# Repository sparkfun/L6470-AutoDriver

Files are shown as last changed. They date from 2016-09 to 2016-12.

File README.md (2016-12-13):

SparkFun AutoDriver - Stepper Motor Driver
==========================================

AutoDriver  

[*AutoDriver (BOB-13752)*](https://www.sparkfun.com/products/13752)

The AutoDriver is a bipolar stepper driver based on the ST Micro L6470 chip. It allows a processor to control a single 3A bipolar stepper motor across an 8-45V supply range.

Repository Contents
-------------------
* **/Hardware** - All Eagle design files (.brd, .sch)
* **/Libraries** - All Arduino libraries and board examples
* **/Production** - Test bed files and production panel files

Documentation
--------------
* **[Library](https://github.com/sparkfun/SparkFun_AutoDriver_Arduino_Library)** - Arduino library for the AutoDriver.
* **[Hookup Guide](https://learn.sparkfun.com/tutorials/getting-started-with-the-autodriver---v13)** - Basic hookup guide for the Auto Driver.
* **[SparkFun Fritzing repo](https://github.com/sparkfun/Fritzing_Parts)** - Fritzing diagrams for SparkFun products.
* **[SparkFun 3D Model repo](https://github.com/sparkfun/3D_Models)** - 3D models of SparkFun products. 
* **[SparkFun Graphical Datasheets](https://github.com/sparkfun/Graphical_Datasheets)** -Graphical Datasheets for various SparkFun products.

License Information
-------------------

This product is _**open source**_! 

Please review the LICENSE.md file for license information. 

If you have any questions or concerns on licensing, please contact techsupport@sparkfun.com.

Distributed as-is; no warranty is given.

- Your friends at SparkFun.

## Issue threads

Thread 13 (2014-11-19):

Board issues

lewispg228, 2014-11-19:
1) I think we may want to go with the "PANASONIC_E" package for C3. "PANASONIC_C" is the current package, and when you compare it to a scaled product image, it looks too small:
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

2) Dimension line is 0.010, should be 0.008

3) Would it be beneficial if we pre-populated all of the PTH connectors with the SS? If so, we should move the packages to locking style.

4) Please add test point to 3.3V net

5) JP1 2 3 and 4, and R4 do not have >NAME text object in the package.

6) remove the M.Hord text object on tvalues

7) add dimension measurements onto the measures layer 47

8) The HTSSOP28 packages used on the L6470 needs it's outline silk bumped up to 8 mil. same thing for trimpot (R4)

9) What does the switch do? Can we add any schematic note and/or board silk to be more descriptive than "SWITCH"

10) Can we add some silk boxes around the GND MOTOR pins, and POWER pins to more clearly shot that each pin is doubled up.

11) Can we scoot the 3 way jumper out a bit so the labeling can be more uniform (that is, each label being on each outer side of the jumper) Or just scoot C8 up a bit so the "3.3V" can live directly above jumper.

12) Looks like there are 4 active low pins on the L6470. We should probably get those updated in the symbol to show that.

13) We should probably add some silk to label the trimpot. Maybe just "Trimpot to ADCIN".

lewispg228, 2015-01-14:
Sorry to have left this linger so long. I'm not sure how it fell off my radar.

I just did some printing and it looks like all the panasonic packages are wrong. But there is a device for the NIC 10X10.5 cap that is correct.

mhord, 2015-04-22:
The NIC package is the one that's on there; the first round of protos (with the bad cam job) came back looking good.

lewispg228, 2015-04-22:
Sorry I was looking at the wrong tree. Here's my review of v11 on the qc-rev:

1) Does the frame have the proper CC attribution? (Frame- Letter/Ledger, CC 4.0) [NO]
comment: Needs latest frame to avoid panelization problem regarding copper version

2) Is 'Revised by:' and 'reviser name' included? [YES]
comment: move back into frame box

3) Are dashed grey lines ('info' eagle layer 97) used to clearly separate different areas? [NO]
comment: dashed lines are currently on symbols layer, should be info

4) Is the VCC range clearly labeled? [NO]
comment: needs vcc range in sch

5) Do any parts have unnecessary values (Eagle has autoset the package as the value)? [YES]
comment: SJ3 JP1 JP2

6) Does your 4 layer board include mike hord's special '1' '2' '3' '4' in the copper of each layer? [NO]
comment: this is nice fore gerber verification

7) Are any vias intended to be used as PTH headers (they shouldn't be)? [YES]
comment: The CSN via should be an actual M01 device

8) Is there a correct version number in the copper? [NO]
comment: copper version is outside dimension of board

9) Are measurements included for outer dimension and standoffs (Eagle layer 47)? [NO]
comment: needs measures

mhord, 2015-04-22:
Killer. I'll make these changes along with anything we find out from this round of re-cammed protos.

lewispg228, 2015-04-24:
Thanks Mike.

I think production (Nick Harmier or Austin Metzger) is waiting for us to finalize this review before they re-cam it up and order another round of protos.

They won't order any protos until they see (1) uploaded complete review Excell doc and (2) the review flag set to "+".

mhord, 2015-04-30:
Fixed.

Closed 2015-04-30.

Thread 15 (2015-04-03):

Making the library compatible with Teensy

PheiPheiPhei, 2015-04-03:
Hi!

[I came across a simple fix that will make the library compatible with Teensy microcontrollers.](https://forum.pjrc.com/threads/28094-L6470-AutoDriver-stepper-driver-and-the-Teensy-3-1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) Simply declaring all chars explicitly as signed will fix it.

ToniCorinne, 2016-03-09:
Hi -we'd love it if you added a pull request with this fix to the main library repository [here](https://github.com/sparkfun/SparkFun_AutoDriver_Arduino_Library). That will allow us to give you credit for the fix.

Thanks!

PheiPheiPhei, 2016-03-09:
Hi!

I'm sadly a pretty big noob with Git and don't know how to do that. But go
ahead, I don't insist on credit. :)

2016-03-09 1:18 GMT+01:00 Toni Klopfenstein <notifications@github.com>:

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

christophepersoz, 2016-04-04:
Hello guys,

I'm trying to make the library working with a simple example (run, stop, back run), but it seems that something is going wrong just after sending the goToDir command. As soon as the stepper start to run until the position and after it reach the position the loop() completely stop.
Do you have this kind of issue too ?

Thanks

christophepersoz, 2016-04-25:
In order to make the library completely compatible with Teensy I had to change the SparkFunAutoDriverCommands.cpp in the same way that @PheiPheiPhei did on xferParam() and signed all the char in the file. That way, when you call GoTo() command or any other referring to SPIXfer() the behavior is now OK.

I hope it could help.

mhord, 2016-08-16:
Fixed during refactoring by changing data type to int8_t (aka signed char) from char. Thanks for the tip!

Closed 2016-08-16.

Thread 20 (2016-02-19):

dSPIN_support:165 error

castfxman, 2016-02-19:
Hello,

I have used your example with success and recent reinstalled my 1.5.3 IDE and am getting a new error on line 165 of dSPIN_support it looks like

`  dSPIN_support:165: error: 'SPI_CLOCK_DIV16' was not declared in this scope`

Any ideas where this error could be coming from?  Thanks!

mgrusin, 2016-02-22:
It looks like setClockDivider() may have been depreciated: https://www.arduino.cc/en/Reference/SPISetClockDivider. We apologize for the inconvenience; the newest Arduino IDEs have been breaking a lot of things.

Thanks for the error report, we'll look into it!

castfxman, 2016-02-22:
Yes, in 1.5.8 version did not get this error, I tried to not include the SPI_CLOCK_DIV16 line in the 1.5.3 version which I think pumped unregulated hertz into the boards motor drivers.  I did in fact fry/smoke/burnout a couple L6470 drivers by eliminating that SPI _Clock_div16 line, but it is properly declared in 1.5.8.  SPI.h file.  So I'm using that or later from now on.

Closed 2016-02-22.

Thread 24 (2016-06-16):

Renumber solder jumpers and sj description text

mhord, 2016-06-16:

mhord, 2016-06-16:
Fixed...made into SJ3 (SJ2 is the PGND-GND jumper)

Closed 2016-06-16.

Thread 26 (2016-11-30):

AutoDriver ABS_POS problems

philk557, 2016-11-30:
About two months ago I ordered an L6470 AutoDrive V13 board from SparkFun to use with a machine tool rotary table. I have gotten the board to work with an Arduino Mega and a 34 vdc power supply.

However the position count from ADboard.getParam (ABS_POS) has problems:

1.     Even with the board set to full stepping, ADboard.configStepMode(STEP_FS),
       ABS_POS increments by about 128 microsteps instead of full steps.

2.     The count appears to be modulo 2**16 unsigned instead of 2**21 two’s complement.

For example (the decimal numbers are 2**16 unsigned):

When ABS_POS is incremented from  0x007FFF (32,767), ABS_POS is set to 0x3F8000 (32,768).
When ABS_POS is incremented from  0x3FFFFF (65,535), ABS_POS is set to 0x000000.
When ABS_POS is decremented from 0x000000,             ABS_POS is set to 0x3FFFFF (65,535)
When ABS_POS is decremented from 0x3F8000 (32,768), ABS_POS is set to 0x007FFF (32,767).

ADboard.getPos() interprets the count as 2**21 two’s complement.

When  the count reaches 0x007FFF (32,767), it rolls over to 0xFFFF8000 (-32,768)..

Following are portions of a monitor log file of readings once a second.

get_pos is the value return by long getPos(); first HEX then DEC.
ABS_POS is the value returned by unsigned long getParam(ABS_POS), first HEX the DEC
&0x00FFFF is the ABS_POS value masked by &0x00FFFF, first HEX then DEC.

  10:2:22 Run FWD 1.00 steps/sec for 20 secs
  get_pos: 7EB9 32441  ABS_POS: 7EB9  &0x00FFFF 7EB9 32441
  get_pos: 7F3B 32571  ABS_POS: 7F3B  &0x00FFFF 7F3B 32571
  get_pos: 7FBE 32702  ABS_POS: 7FBE  &0x00FFFF 7FBE 32702
  get_pos: FFFF8040 -32704  ABS_POS: 3F8040  &0x00FFFF 8040 32832
  get_pos: FFFF80C2 -32574  ABS_POS: 3F80C2  &0x00FFFF 80C2 32962
  get_pos: FFFF8144 -32444  ABS_POS: 3F8144  &0x00FFFF 8144 33092

  get_pos: FFFFFE87 -377  ABS_POS: 3FFE87  &0x00FFFF FE87 65159
  get_pos: FFFFFF09 -247  ABS_POS: 3FFF09  &0x00FFFF FF09 65289
  get_pos: FFFFFF8B -117  ABS_POS: 3FFF8B  &0x00FFFF FF8B 65419
  get_pos: D 13  ABS_POS: D  &0x00FFFF D 13
  get_pos: 8F 143  ABS_POS: 8F  &0x00FFFF 8F 143
  get_pos: 112 274  ABS_POS: 112  &0x00FFFF 112 274

10:17:54 Run REV 1.00 steps/sec for 20 secs
  get_pos: 174 372  ABS_POS: 174  &0x00FFFF 174 372
  get_pos: F1 241  ABS_POS: F1  &0x00FFFF F1 241
  get_pos: 6F 111  ABS_POS: 6F  &0x00FFFF 6F 111
  get_pos: FFFFFFED -19  ABS_POS: 3FFFED  &0x00FFFF FFED 65517
  get_pos: FFFFFF6B -149  ABS_POS: 3FFF6B  &0x00FFFF FF6B 65387
  get_pos: FFFFFEE9 -279  ABS_POS: 3FFEE9  &0x00FFFF FEE9 65257

  get_pos: FFFF8144 -32444  ABS_POS: 3F8144  &0x00FFFF 8144 33092
  get_pos: FFFF80C1 -32575  ABS_POS: 3F80C1  &0x00FFFF 80C1 32961
  get_pos: FFFF803F -32705  ABS_POS: 3F803F  &0x00FFFF 803F 32831
  get_pos: 7FBD 32701  ABS_POS: 7FBD  &0x00FFFF 7FBD 32701
  get_pos: 7F3B 32571  ABS_POS: 7F3A  &0x00FFFF 7F3A 32570
  get_pos: 7EB8 32440  ABS_POS: 7EB8  &0x00FFFF 7EB8 32440

mhord, 2016-11-30:
Give it a try now. I fixed a logic error in the shifting of incoming SPI data that only affected parameters of greater than 16 bits.

philk557, 2016-11-30:
Hello Mike

Great!  You fixed it.

Do I download a new version of the AutoDriver library to get the fix?

Thanks

Phil

At 02:55 PM 11/30/2016, you wrote:

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

mhord, 2016-12-01:
You can either download it, clone it, or pull the changes. Downloading is probably easiest if you aren't already doing a lot of stuff via github.

philk557, 2016-12-02:
Hi Mike

I deleted the old AutoDriver library, download
the AutoDriver ZIP file from GitHub and added the
new library.  I didnt see any change notice in
the header so I assumed I got your fix.

There are still problems.

In the following logs, the first get_pos number
is HEX, the second is DEC and the third is the
difference from the previous reading DEC.  All
get_pos numbers are printed as LONG.  The ABS_POS is HEX.

1.  ADboard.getPos()is still reporting about 130
steps per full step, ADboard.configStepMode(STEP_FS).

11:9:40 Run FWD 1.00 steps/sec for 10 secs
11:9:40   get_pos: 1 1 1  ABS_POS: 3
11:9:42   get_pos: 87 135 134  ABS_POS: 87
11:9:43   get_pos: 109 265 130  ABS_POS: 109
11:9:44   get_pos: 18C 396 131  ABS_POS: 18C
11:9:45   get_pos: 20E 526 130  ABS_POS: 20E
11:9:46   get_pos: 290 656 130  ABS_POS: 290
11:9:47   get_pos: 312 786 130  ABS_POS: 313
11:9:48   get_pos: 395 917 131  ABS_POS: 395
11:9:49   get_pos: 417 1047 130  ABS_POS: 417
11:9:50   get_pos: 499 1177 130  ABS_POS: 49A
11:9:51   get_pos: 51C 1308 131  ABS_POS: 51C
elapsed ms= 11141

2.      Since AB_POS is a 22 bit register with a
signed number, I expected 2FFFFF to overflow to 0?  Not to keep on incrementing

11:12:41 Run FWD 400.00 steps/sec for 30 secs
11:12:51   get_pos: 2D2109 2957577 52226  ABS_POS: 2D2143
11:12:52   get_pos: 2DECDC 3009756 52179  ABS_POS: 2DED16
11:12:53   get_pos: 2EB8F4 3062004 52248  ABS_POS: 2EB92D
11:12:54   get_pos: 2F850B 3114251 52247  ABS_POS: 2F8545
11:12:55   get_pos: 305120 3166496 52245  ABS_POS: 305159
11:12:56   get_pos: 311D28 3218728 52232  ABS_POS: 311D61
11:12:57   get_pos: 31E928 3270952 52224  ABS_POS: 31E962
11:12:58   get_pos: 32B526 3323174 52222  ABS_POS: 32B560

11:13:20   get_pos: 3DF997 4061591 11  ABS_POS: 3DFA50
11:13:21   get_pos: 3EBD37 4111671 50080  ABS_POS: 3EBD70
11:13:22   get_pos: 3F893A 4163898 52227  ABS_POS: 3F8973
11:13:23   get_pos: 5547 21831 -4142067  ABS_POS: 557C
11:13:24   get_pos: 12153 74067 52236  ABS_POS: 12185
11:13:25   get_pos: 1ED64 126308 52241  ABS_POS: 1ED99
11:13:26   get_pos: 2B973 178547 52239  ABS_POS: 2B9A7

3.      Following is what happened when
decrementing past 0.  I expected the next count
to be minus.  It looks like the minus bit wasnt propagated to the left.

11:40:29   get_pos: 18B 395 -130  ABS_POS: 18B
11:40:30   get_pos: 108 264 -131  ABS_POS: 108
11:40:31   get_pos: 86 134 -130  ABS_POS: 86
11:40:32   get_pos: 4 4 -130  ABS_POS: 4
11:40:33   get_pos: 3FFF81 4194177 4194173  ABS_POS: 3FFF81
11:40:34   get_pos: 3FFEFF 4194047 -130  ABS_POS: 3FFEFF
11:40:35   get_pos: 3FFE7D 4193917 -130  ABS_POS: 3FFE7C

At 02:55 PM 11/30/2016, you wrote:

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

mhord, 2016-12-05:
1. Can you post your code somewhere? I can't duplicate the stepping issue. What does the actual motor seem to be doing? If you move forward at 1step/s, does it move a full revolution in the expected time?
2. Overflow of signed integers is left to the compiler author's imagination; there's no standard for it, so anything that happens is fair game. It looks like if you go far enough past -2^21 eventually something weird happens and you end up with a large positive integer. This appears to be how the chip does it, based on my observations of the data coming directly from the chip.
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
mhord, 2016-12-06:
Found it. On line 957 you issue the "resetDev()" command, which is going to reset all the registers to their power-on state. The chip starts up with 128 microsteps/step as the default. Try commenting out that line and see what it gives you.

philk557, 2016-12-07:
Hello Mike

Thank you for finding that!  I appreciate it.

After moving the resetDev ahead of all the config
settings, the steeper wouldn't run.  The
setOCThreshold(OC_1500mA) was too low and OC
shutdown occurred.  I changed the threshold to 2250 ma and now it works fine.

Let me suggest that in
https://learn.sparkfun.com/tutorials/getting-started-with-the-autodriver---v13#arduino-library---operation
you add to

void resetDev();

Equivalent to toggling the reset pin, but
performed through an internal software register
control on the L6470 chip. If you dont want to
use a pin for reset, this option is for you.

a note that parameters are reset to the values
listed on page 40 of the L6470 datasheet.

I still can't add the latest ZIP library file
from the AutoDriver GitHub respository.  Arduino
IDE Add ZIP library says "Specified folder/zip
file does not contain a valid library".

Thanks again

Phil

At 08:59 AM 12/6/2016, you wrote:

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

mhord, 2016-12-12:
I'll make a note in the tutorial about what exactly that reset function does.

Do you know how to manually install the library? Just extract the archive and drag the folder into the "libraries" directory inside your sketchbook folder. See if it works doing that and I'll see if I can't figure out why the IDE doesn't like it.

mhord, 2016-12-12:
Also, make sure you're downloading the zip file of *just* the library, not the library and hardware files both. [Here is the link](https://github.com/sparkfun/SparkFun_AutoDriver_Arduino_Library) to the library repository.

MarcusWolschon, 2017-02-09:
Is this issue still open or did someone forget to close it?

mhord, 2017-02-09:
It should have been closed. Sorry about that!

philk557, 2017-02-09:
Sorry, forgot I needed to close it. Mike H. helped me resolve the problem.

Phil Keys

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

Closed 2017-02-09.

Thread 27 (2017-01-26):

hardHiZ does not put motor in High-Impedance mode

alborzs, 2017-01-26:
calling `hardHiZ()` in `v13` of this library does NOT put the motor in high-impedance mode.
I have looked at the code to find the issue but I have not been successful yet.
What does work and put the motor in high-impedance mode is `hardStop()`.
You are welcome to test this for yourself.

mhord, 2017-01-27:
Th;is is not consistent with my observations. hardStop() hard stops the board, putting the board in Hold mode so that the shaft resists being turned. hardHiZ() puts the board into HiZ mode, where there is no load on the coils, allowing the shaft to spin more or less freely.

Closed 2017-01-27.

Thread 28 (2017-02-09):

Mechanical drawing

MarcusWolschon, 2017-02-09:
A simple mechanical drawing that provides the location of the mounting holes and the board dimensions would be very nice.
Not everyone has EAGLE or knows how to use it to get a DXF these from the .brd file.

mhord, 2017-02-09:
We've (globally) elected not to do this since there is a free version of Eagle available and we include measurements in the board design files. We realize that it doesn't work for everyone, but neither will dxf, svg, or any other format we choose. Eagle is simply the least common denominator.

MarcusWolschon, 2017-02-13:
So for non-personal or commercial use the user is expected to buy Eagle or take their own meassurements? This is rediculus.

mhord, 2017-02-13:
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

Here's a PNG of the mechanical layout. You bring up an interesting point regarding licensing of EAGLE. I'll bring the topic up for debate again.

Closed 2017-02-09.

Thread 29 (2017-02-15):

Issues with "GetPos()"

Vachefolle, 2017-02-15:
Hi,

I've an issue with the function GetPos(). Effectively, if we see this picture :
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

When I move the motor, the getPos function display the current position of motors. If I move the motor 100 steps, getPos display 100 steps. If I move 200 steps, getPos display 72 steps, etc. Between 0 and 127, getPos display 0 to 127. But between 128 and 200, we can see 0 to 72...

I really don't know where the problem comes from.

The last version of AutoDriver library is : 1.3.2.
Motor : [http://www.omc-stepperonline.com/gear-ratio-511-planetary-gearbox-with-nema-14-stepper-motor-14hs130804spg51-p-138.html](url)
AutoDriver : [https://www.sparkfun.com/products/11611](url)
OS : Ubuntu 16.04

Somebody had the same problem and fixed it ?

Thanks !

PS : my code :

```
void setupPIN()
{
	//Setup wiringPi
	wiringPiSetup();

	//Setup PIN RESET/BUSY/ENDPOS A & B
	pinMode(PIN_RESET, 				OUTPUT); //PIN RESET
	pinMode(PIN_BUSY, 				INPUT);  //PIN BUSY
	pinMode(PIN_LASER, 				OUTPUT);  //PIN LASER
	pinMode(PIN_A_ENDPOSITION_A, 	INPUT);
	pinMode(PIN_A_ENDPOSITION_B, 	INPUT);
	pinMode(PIN_B_ENDPOSITION_A, 	INPUT);
	pinMode(PIN_B_ENDPOSITION_B, 	INPUT);

	//Open port CE0
	digitalWrite(PIN_CS, HIGH);

	//Reset Board A & B
	digitalWrite(PIN_RESET, LOW);
	digitalWrite(PIN_RESET, HIGH);
}

void setupBOARD_b()
{
	boardA.configSyncPin(PIN_BUSY, 0);
	boardA.configStepMode(STEP_FS);
	boardA.setOscMode(INT_16MHZ_OSCOUT_16MHZ);
	boardA.setMinSpeed(0);
	boardA.setMaxSpeed(500);
	boardA.setAcc(3000);

	boardB.configSyncPin(PIN_BUSY, 0);
	boardB.configStepMode(STEP_FS);
	boardA.setOscMode(INT_16MHZ_OSCOUT_16MHZ);
	boardB.setMinSpeed(0);
	boardB.setMaxSpeed(500);
	boardB.setAcc(3000);
}
int main()
{
	setupPIN();
	setupBOARD_b();
	long step;
	while (1)
	{
		boardB.resetPos();
		cout << "Input a step : "; cin >> step;
		boardB.move(1,step);
		while(boardB.busyCheck()){
		}
		cout << "test = " <<  boardB.getPos() << endl;
		delayy(1000);
		boardB.move(0,step);
	}
	return 0;
}
```

Vachefolle, 2017-02-15:
But when I tell it to move 200 steps, motor moves 200 steps (because it crossed 2 times the distance of 100 steps). So, the problem doesn't come from motors... :/

mhord, 2017-02-20:
I can't duplicate this under Arduino 1.8.1. A simple application which turns the motor on for ten seconds and prints the position ten times a second yields the results I'd expect.

I'm going to suggest that you get the library directly from the library repository, just to make sure it is, in fact, the most recent version. [Here's a link to that page.](https://github.com/sparkfun/SparkFun_AutoDriver_Arduino_Library)

Vachefolle, 2017-02-20:
Thanks for your answer. I use a raspberry Pi 3 ^^

And I already got back the last version. But don't worry. I found a solution to have the correct position. Increment and decrement a global variable which get back the movement :

**Exemple :**
Move left 100 steps (direction : 1, getPosA +=  100) then move right 50 steps ( direction : 0, getPosA -= 50) then etc.

Same for the second motor with getPosB.

mhord, 2017-02-20:
Okay, I'm glad you have a workaround. It looks to me like some kind of overflow error or something, since it breaks at 128, maybe there is a place where the data flows through an int8_t datatype?

Vachefolle, 2017-02-21:
I thought about the same problem (kind of overflow). Maybe but where ?
Do you exactly want my project (part of autodriver library)? Maybe you'll find something that pass before my eyes ! :/

It isn't in the rush, but I'll reuse this board within a short time and I'll find this problem again...

In any case, thank for your answers !

Closed 2017-03-08.

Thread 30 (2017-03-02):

Uploading Example Sketch to Arduino Mega 2560  Hangs

MeijinGandalf, 2017-03-02:
I was having issues uploading the SparkFunGetSetParamTest sketch to the Arduino Mega 2560. I found that any Serial.print or Serial.println that had three exclamation points in a row "!!!" cause the upload to hang. I was able to comment those lines out and get the sketch to upload.  Changing those to two in a row also fixed the uploading issue.  Have you seen this issue yourself?

mhord, 2017-03-02:
I haven't tried it on the Arduino Mega. Perhaps something in the bootloader uses the exclamation point as an escape character?

MeijinGandalf, 2017-03-17:
I am not sure.  When looking through a bunch of forums i found another person that had the same problem when trying to upload a different problem. When uploading to the Uno R3 there was no problem.

mhord, 2017-03-17:
My tech support team tells me that this is, in fact, a known issue with the bootloader on the Mega. It treats three exclamation points as an escape sequence. The only fix is to remove one or more exclamation points.

Closed 2017-03-17.

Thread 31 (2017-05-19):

SparkFun Fritzing repo - Fritzing diagrams for SparkFun products.

MarcusWolschon, 2017-05-19:
In README.md you mention the "SparkFun Fritzing repo" but that one doesn't seem to contain the L6470-Autodrive board in "products"

loricrotser, 2018-08-17:
Just checked in the fritzing part for v13. v10 should be uploaded sometime in the next week.
[https://github.com/sparkfun/Fritzing_Parts/blob/master/products/13752_sfe_autodriver_stepper_motor_v13.fzpz](https://github.com/sparkfun/Fritzing_Parts/blob/master/products/13752_sfe_autodriver_stepper_motor_v13.fzpz)

Closed 2018-08-17.

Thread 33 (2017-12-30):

Hi! How does one change the ‘SDO to:’ jumper setting to ‘Next bd’ on the Autodriver v13 board? Thank you!

holstenholsten, 2017-12-30:

mhord, 2018-01-02:
You'll need some desoldering wick to remove the solder that's present on the jumper, then to solder the two pads on the "Next bd" side of the jumper.

holstenholsten, 2018-01-02:
Thank you for the quick reply. Should I do this on both boards, or just the first one?

mhord, 2018-01-03:
The first board in the series only.

Closed 2018-01-02.

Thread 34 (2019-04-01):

goto/gotodir functions do not work

wandergeek, 2019-04-01:
Hello,

I seem to be having issues getting the `goTo` and `goToDir` functions to work. When the function runs, the motor moves quickly and then stops responding. I see serial messages from my program indicating that the micro is still alive. I should note that the `goToDir` motor motion is fast and not smooth like `run`.

I can also report that the `run` function works fine. Source examples for both below:

## Working
```C
void loop() {
      if (dir == 1) {
        Serial.println("going fwd");
        boardA.run(FWD, 100);
      } else {
        Serial.println("going bwd");
        boardA.run(REV, 100);
    }
      Serial.println("zzzz 2 secs");
      delay(2000);
      dir*=-1;
      Serial.println("soft stopping");
      boardA.softStop();
      Serial.println("checking busy");
      while (boardA.busyCheck()) {
          Serial.print("busy pos");
          Serial.println(boardA.getPos());
      }
}
```
## Not working

```C
void loop() {
      if (dir == 1) {
        Serial.println("going fwd");
        boardA.goToDir(FWD,400);
      } else {
        Serial.println("going bwd");
        boardA.goToDir(REV,400);
    }
      Serial.println("zzzz 2 secs");
      delay(2000);
      dir*=-1;
      Serial.println("soft stoppping");
      boardA.softStop();
      Serial.println("checking busy");
      while (boardA.busyCheck()) {
          Serial.print("busy pos");
          Serial.println(boardA.getPos());
      }
}
```

wandergeek, 2019-04-07:
Is there any extra info I can provide? :)

edspark, 2019-04-22:
Sorry for the very delayed response. Shortly after I looked after your issue, I was called away suddenly from work because my wife went into labor. I'm looking into it now.

edspark, 2019-04-23:
Hello @wandergeek, as far as I can tell your code runs fine for me. I made a slight modification switching the `boardA.busyCheck()` function with your delay so that I could get a readout of the stepper motor's position as it was turning, and _then_ delaying for 2 seconds.  Please see the attached serial output:

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

I think seeing all of your code may help me determine what the issue is, and stating the power you're giving your motors. Below I've linked the code in its' entirety that I'm using to run the motors, perhaps that would be more helpful.

```C++
#include <SparkFunAutoDriver.h>
#include <SPI.h>

int CSPin = 10;
int boardPos = 0;
int resetPin = A4;
int busyPin = A5;
int dir = 1;

AutoDriver boardA(boardPos, CSPin, resetPin, busyPin);

void setup() {

  Serial.begin(115200);
  Serial.println("Motors and stuff.");
  boardA.SPIPortConnect(&SPI);
  SPI.begin();
  SPI.setDataMode(SPI_MODE3);

}

void loop() {

  if (dir == 1) {
    Serial.println("Forward...");
    boardA.goToDir(FWD, 400);
  }
  else {
    Serial.println("Backward...");
    boardA.goToDir(REV, 400);
  }

  while (boardA.busyCheck()) {
      Serial.print("Board Position: ");
      Serial.println(boardA.getPos());
  }

  Serial.println("Stopping...");
  delay(2000);
  dir *= -1;
  boardA.softStop();

}
```

edspark, 2019-04-23:
I'm going to close this for the time being, please reopen if you have more questions.

Closed 2019-04-23.

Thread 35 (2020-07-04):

feature request: L6480  version (external Mosfets)

MarcusWolschon, 2020-07-04:
Let's create an L6480 (instead of L6470 ) version.
They allow up to 82V and use external mosfests.
So we can choose our own maximum current.
That would allow the use with stronger steppers (e.g. in the base of a robotic arm, steppers for vehicle movement or CNC work).

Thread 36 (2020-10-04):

Timing issue using Teensy 4.0

JLBolinger, 2020-10-04:
I have found that there appears to be a timing issue when using the L6470 library won a Teensy 4.0.  The Teensy sends the next byte before the previous was processed by the L6470.

I have traced the problem to the SPIXfer() function, and have made it work by inserting delays at strategic locations

byte AutoDriver::SPIXfer(byte data)
{
byte dataPacket[_numBoards];
int i;
for (i=0; i < _numBoards; i++)
{
dataPacket[i] = 0;
}
dataPacket[_position] = data;
digitalWrite(_CSPin, LOW);
delayMicroseconds(1);
_SPI->beginTransaction(SPISettings(4000000, MSBFIRST, SPI_MODE3));
_SPI->transfer(dataPacket, _numBoards);
delayMicroseconds(1);
_SPI->endTransaction();
digitalWrite(_CSPin, HIGH);
delayMicroseconds(5);
return dataPacket[_position];
}

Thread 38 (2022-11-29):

AutoDriver quits running, locks up and requires reset during long move/run commands

hemsingd, 2022-11-29:
Whenever I initiate long motion commands the AutoDriver will lock up and require a reset.  Sometimes it's just the AutoDriver board in which case a boardname.resetDev() will get it to respond.  Other times it's both driver boards and the SAMD51 Thing Plus board that need a physical reset.

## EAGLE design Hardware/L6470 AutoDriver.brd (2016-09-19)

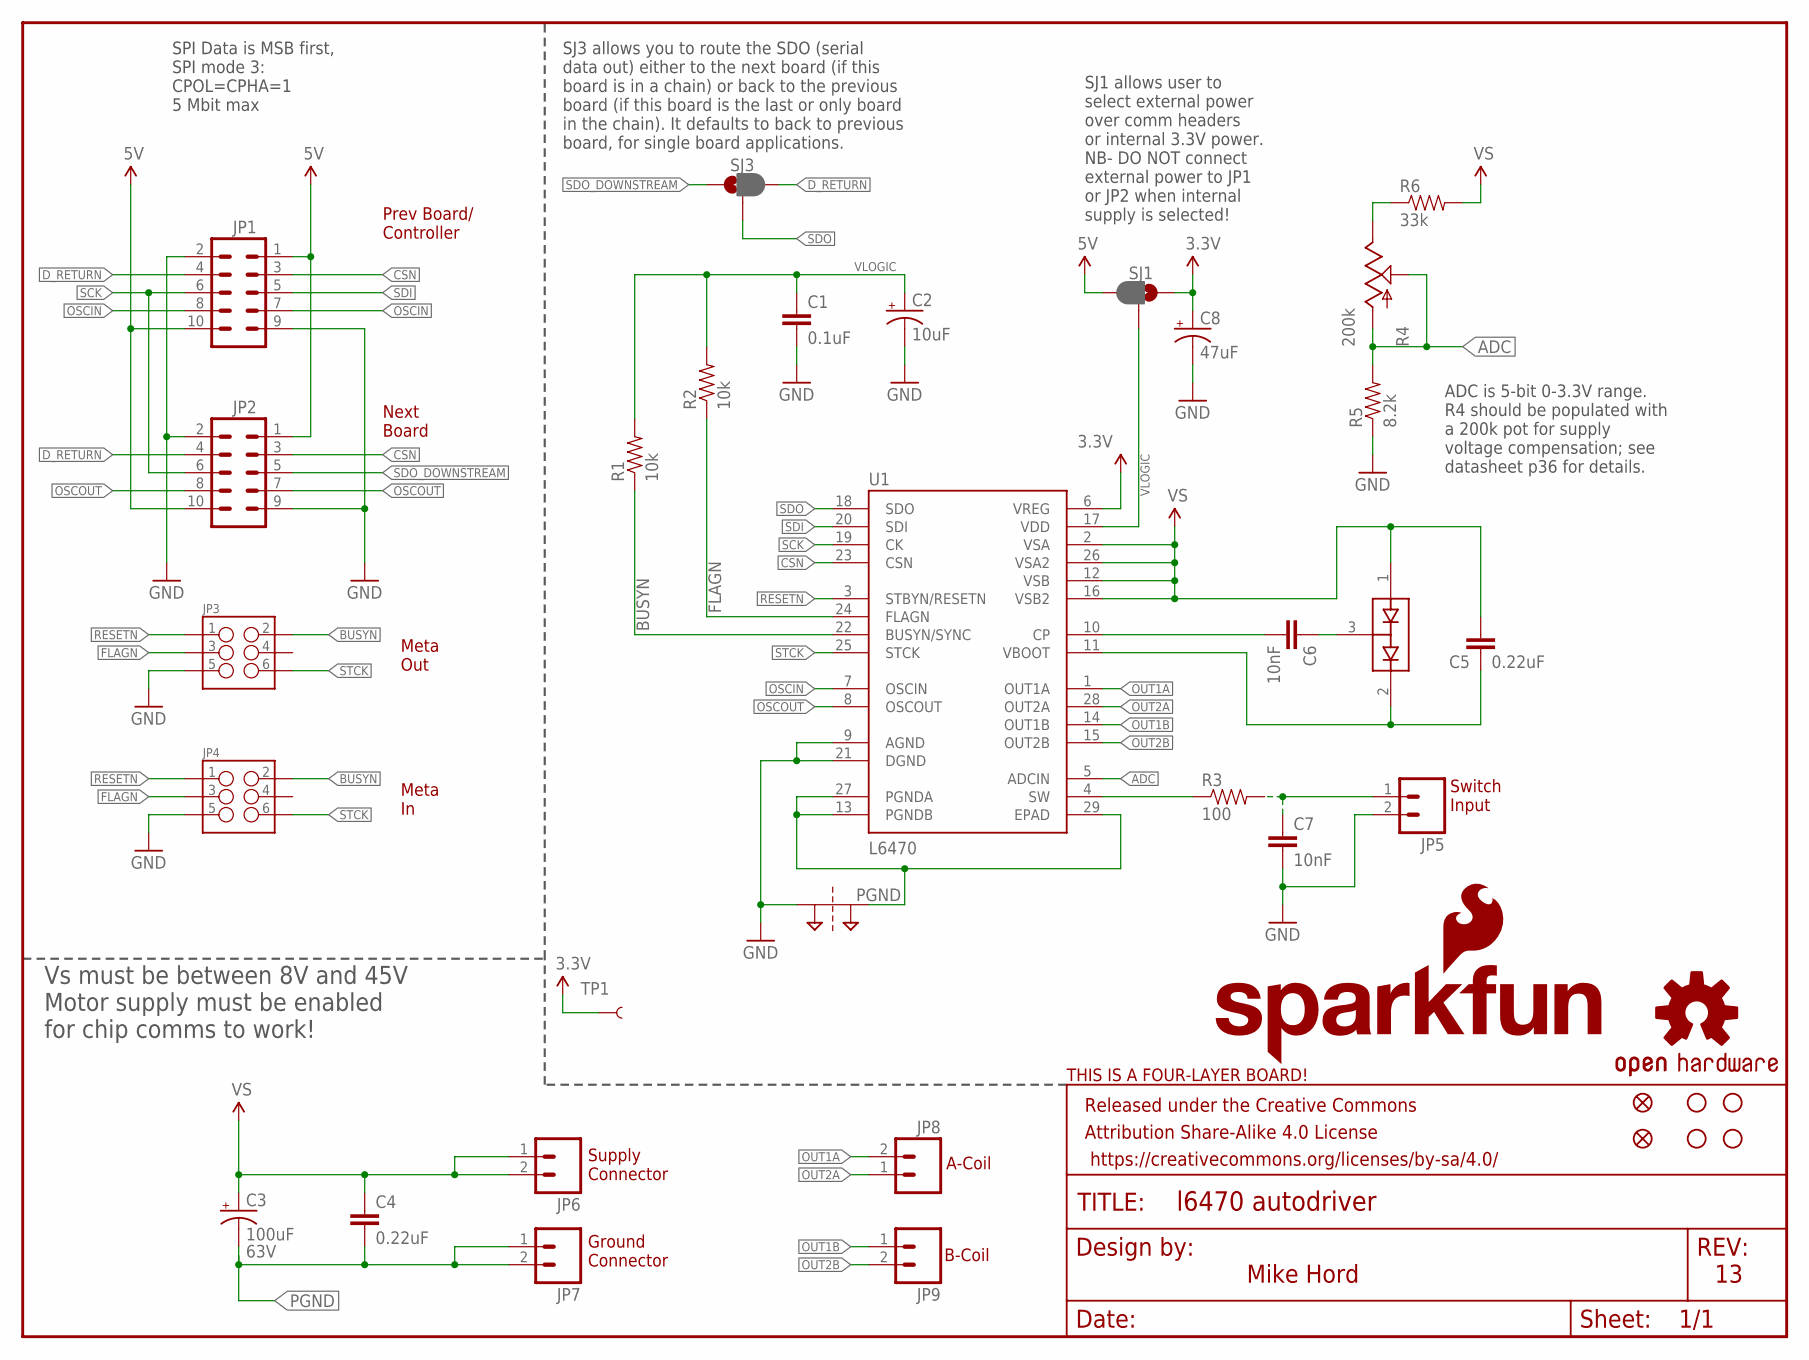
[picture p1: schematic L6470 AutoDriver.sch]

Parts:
C1: 0.1uF; 0603-CAP
C2: 10uF; EIA3216
C3: 100uF; NIC_10X10.5_CAP
C4, C5: 0.22uF; 0603-CAP
C6, C7: 10nF; 0603-CAP
C8: 47uF; EIA3528
D1: BAV99; SOT23-3
FID1, FID2: FIDUCIALUFIDUCIAL; MICRO-FIDUCIAL
FRAME1: FRAME-LETTER; CREATIVE_COMMONS
JP1, JP2: M05X2SHD; 2X5-SHROUDED
JP3, JP4: M03X2SHROUD; 2X3-SHROUDED
JP5, JP6, JP7, JP8, JP9: M023.5MM; SCREWTERMINAL-3.5MM-2
LOGO1: OSHW-LOGOM; OSHW-LOGO-M
LOGO2: SFE_LOGO_NAME_FLAME.2_INCH; SFE_LOGO_NAME_FLAME_.2
R1, R2: 10k; 0603-RES
R3: 100; 0603-RES
R4: 200k; 3362U
R5: 8.2k; 0603-RES
R6: 33k; 0603-RES
SJ1, SJ3: JUMPER-PAD-3-2OF3_NC_BY_PASTE; PAD-JUMPER-3-2OF3_NC_BY_PASTE_YES_SILK_FULL_BOX
SJ2: 2PT_GND_TIE
STANDOFF1, STANDOFF2, STANDOFF3, STANDOFF4: STAND-OFF
TP1: TEST-POINTTP_15TH_THRU; TP_15TH
U1: L6470; HTSSOP28
U$4: FOUR_LAYER_WARNING

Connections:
3.3V: C8.A (+), SJ1.1, TP1.P$1, U1.6 (VREG)
5V: JP1.1, JP1.10, JP2.1, JP2.10, SJ1.3
ADC: R4.P$2 (S), R4.P$3 (A), R5.2, U1.5 (ADCIN)
BUSYN: JP3.2, JP4.2, R1.1, U1.22 (BUSYN/SYNC)
CP_HIGH: C6.1, D1.3 (COM)
CSN: JP1.3, JP2.3, U1.23 (CSN)
D_RETURN: JP1.4, JP2.4, SJ3.3
FLAGN: JP3.3, JP4.3, R2.1, U1.24 (FLAGN)
GND: C1.2, C2.C (-), C7.2, C8.C (-), JP1.2, JP1.9, JP2.2, JP2.9, JP3.5, JP4.5, JP5.2, R5.1, SJ2.P$1, U1.9 (AGND), U1.21 (DGND)
unnamed: R4.P$1 (E), R6.1
OSCIN: JP1.7, JP1.8, U1.7 (OSCIN)
OSCOUT: JP2.7, JP2.8, U1.8 (OSCOUT)
OUT1A: JP8.2, U1.1 (OUT1A)
OUT1B: JP9.1, U1.14 (OUT1B)
OUT2A: JP8.1, U1.28 (OUT2A)
OUT2B: JP9.2, U1.15 (OUT2B)
PGND: C3.-, C4.2, JP7.1, JP7.2, SJ2.P$2, U1.13 (PGNDB), U1.27 (PGNDA), U1.29 (EPAD)
RESETN: JP3.1, JP4.1, U1.3 (STBYN/RESETN)
SCK: JP1.6, JP2.6, U1.19 (CK)
SDI: JP1.5, U1.20 (SDI)
SDO: SJ3.2, U1.18 (SDO)
SDO_DOWNSTREAM: JP2.5, SJ3.1
STCK: JP3.6, JP4.6, U1.25 (STCK)
SWITCH_INPUT: C7.1, JP5.1, R3.2
SWITCH_SIG: R3.1, U1.4 (SW)
VLOGIC: C1.1, C2.A (+), R1.2, R2.2, SJ1.2, U1.17 (VDD)
VS: C3.+, C4.1, C5.2, D1.1 (A1), JP6.1, JP6.2, R6.2, U1.2 (VSA), U1.12 (VSB), U1.16 (VSB2), U1.26 (VSA2)
V_BOOT: C5.1, D1.2 (C2), U1.11 (VBOOT)
V_CP: C6.2, U1.10 (CP)

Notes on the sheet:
63V
Switch Input
B-Coil
A-Coil
Supply Connector
Ground Connector
SJ1 allows user to select external power over comm headers or internal 3.3V power. NB- DO NOT connect external power to JP1 or JP2 when internal supply is selected!
Next Board
Prev Board/ Controller
Meta Out
Meta In
ADC is 5-bit 0-3.3V range. R4 should be populated with a 200k pot for supply voltage compensation; see datasheet p36 for details.
SPI Data is MSB first, SPI mode 3: CPOL=CPHA=1 5 Mbit max
Mike Hord
Vs must be between 8V and 45V Motor supply must be enabled for chip comms to work!
SJ3 allows you to route the SDO (serial data out) either to the next board (if this board is in a chain) or back to the previous board (if this board is the last or only board in the chain). It defaults to back to previous board, for single board applications.

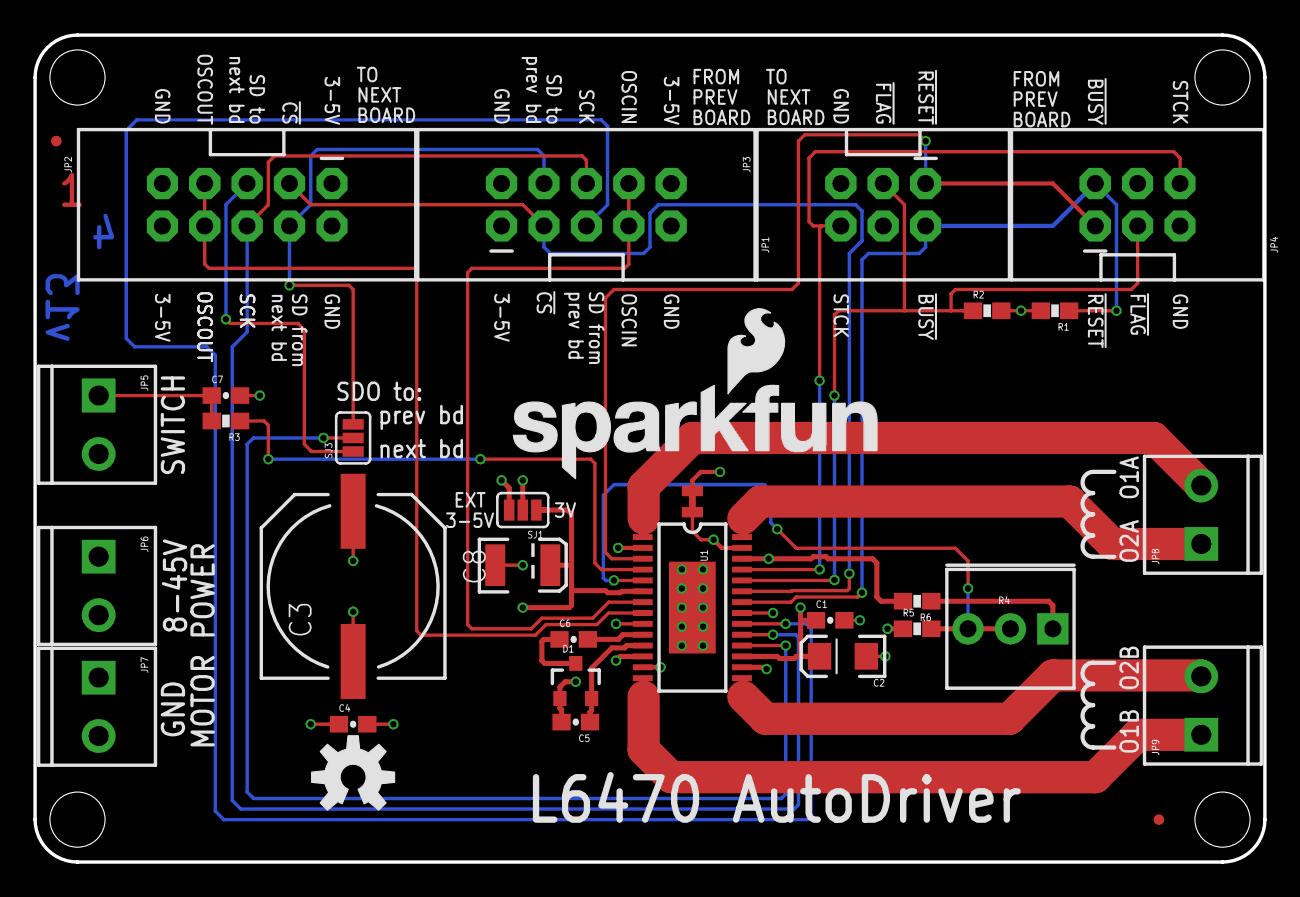
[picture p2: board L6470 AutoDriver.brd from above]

Board: 4 copper layers, 73.7 x 49.5 mm, 39 parts (0 on the bottom side), 29 nets.

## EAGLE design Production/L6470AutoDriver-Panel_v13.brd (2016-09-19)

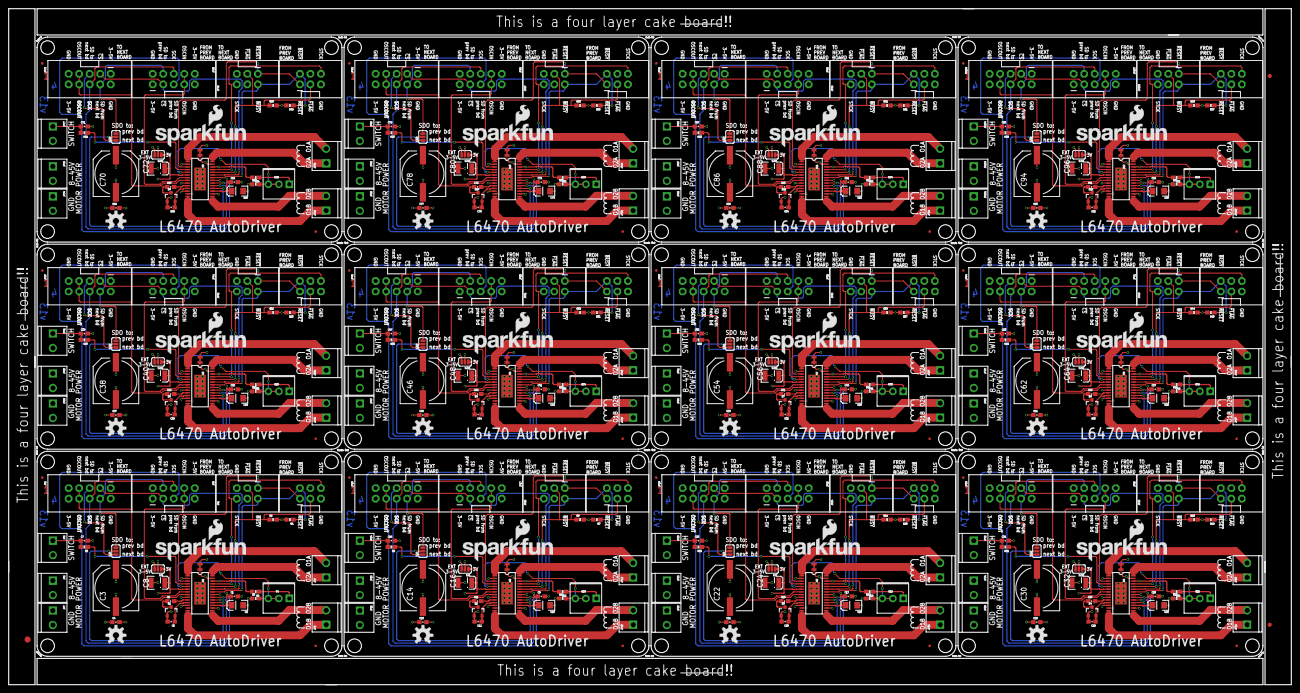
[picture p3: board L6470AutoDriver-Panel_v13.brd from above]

Board: 4 copper layers, 309.9 x 163.3 mm, 447 parts (0 on the bottom side), 348 nets.

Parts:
C1, C9, C17, C25, C33, C41, C49, C57, C65, C73, C81, C89: 0.1uF; 0603-CAP
C2, C10, C18, C26, C34, C42, C50, C58, C66, C74, C82, C90: 10uF; EIA3216
C3, C14, C22, C30, C38, C46, C54, C62, C70, C78, C86, C94: 100uF; NIC_10X10.5_CAP
C4, C5, C12, C13, C20, C21, C28, C29, C36, C37, C44, C45, C52, C53, C60, C61, C68, C69, C76, C77, C84, C85, C92, C93: 0.22uF; 0603-CAP
C6, C7, C11, C15, C19, C23, C27, C31, C35, C39, C43, C47, C51, C55, C59, C63, C67, C71, C75, C79, C83, C87, C91, C95: 10nF; 0603-CAP
C8, C16, C24, C32, C40, C48, C56, C64, C72, C80, C88, C96: 47uF; EIA3528
D1, D2, D3, D4, D5, D6, D7, D8, D9, D10, D11, D12: BAV99; SOT23-3
E$1: FIDUCIAL-1.5X3
E$5, E$6: FIDUCIAL-1X2
FID1, FID2, FID3, FID4, FID5, FID6, FID7, FID8, FID9, FID10, FID11, FID12, FID13, FID14, FID15, FID16, FID17, FID18, FID19, FID20, FID21, FID22, FID23, FID24: FIDUCIALUFIDUCIAL; MICRO-FIDUCIAL
JP1, JP2, JP10, JP15, JP19, JP24, JP28, JP33, JP37, JP42, JP46, JP51, JP55, JP60, JP64, JP69, JP73, JP78, JP82, JP87, JP91, JP96, JP100, JP105: M05X2SHD; 2X5-SHROUDED
JP3, JP4, JP17, JP18, JP26, JP27, JP35, JP36, JP44, JP45, JP53, JP54, JP62, JP63, JP71, JP72, JP80, JP81, JP89, JP90, JP98, JP99, JP107, JP108: 2X3-SHROUDED
JP5, JP6, JP7, JP8, JP9, JP11, JP12, JP13, JP14, JP16, JP20, JP21, JP22, JP23, JP25, JP29, JP30, JP31, JP32, JP34, JP38, JP39, JP40, JP41, JP43, JP47, JP48, JP49, JP50, JP52, JP56, JP57, JP58, JP59, JP61, JP65, JP66, JP67, JP68, JP70, JP74, JP75, JP76, JP77, JP79, JP83, JP84, JP85, JP86, JP88, JP92, JP93, JP94, JP95, JP97, JP101, JP102, JP103, JP104, JP106: SCREWTERMINAL-3.5MM-2
LOGO1, LOGO3, LOGO5, LOGO7, LOGO9, LOGO11, LOGO13, LOGO15, LOGO17, LOGO19, LOGO21, LOGO23: OSHW-LOGOM; OSHW-LOGO-M
LOGO2, LOGO4, LOGO6, LOGO8, LOGO10, LOGO12, LOGO14, LOGO16, LOGO18, LOGO20, LOGO22, LOGO24: SFE_LOGO_NAME_FLAME.2_INCH; SFE_LOGO_NAME_FLAME_.2
R1, R2, R7, R8, R13, R14, R19, R20, R25, R26, R31, R32, R37, R38, R43, R44, R49, R50, R55, R56, R61, R62, R67, R68: 10k; 0603-RES
R3, R9, R15, R21, R27, R33, R39, R45, R51, R57, R63, R69: 100; 0603-RES
R4, R10, R16, R22, R28, R34, R40, R46, R52, R58, R64, R70: 200k; 3362U
R5, R11, R17, R23, R29, R35, R41, R47, R53, R59, R65, R71: 8.2k; 0603-RES
R6, R12, R18, R24, R30, R36, R42, R48, R54, R60, R66, R72: 33k; 0603-RES
SJ1, SJ3, SJ4, SJ6, SJ7, SJ9, SJ10, SJ12, SJ13, SJ15, SJ16, SJ18, SJ19, SJ21, SJ22, SJ24, SJ25, SJ27, SJ28, SJ30, SJ31, SJ33, SJ34, SJ36: JUMPER-PAD-3-2OF3_NC_BY_PASTE; PAD-JUMPER-3-2OF3_NC_BY_PASTE_YES_SILK_FULL_BOX
SJ2, SJ5, SJ8, SJ11, SJ14, SJ17, SJ20, SJ23, SJ26, SJ29, SJ32, SJ35: 2PT_GND_TIE
STANDOFF1, STANDOFF2, STANDOFF3, STANDOFF4, STANDOFF5, STANDOFF6, STANDOFF7, STANDOFF8, STANDOFF9, STANDOFF10, STANDOFF11, STANDOFF12, STANDOFF13, STANDOFF14, STANDOFF15, STANDOFF16, STANDOFF17, STANDOFF18, STANDOFF19, STANDOFF20, STANDOFF21, STANDOFF22, STANDOFF23, STANDOFF24, STANDOFF25, STANDOFF26, STANDOFF27, STANDOFF28, STANDOFF29, STANDOFF30, STANDOFF31, STANDOFF32, STANDOFF33, STANDOFF34, STANDOFF35, STANDOFF36, STANDOFF37, STANDOFF38, STANDOFF39, STANDOFF40, STANDOFF41, STANDOFF42, STANDOFF43, STANDOFF44, STANDOFF45, STANDOFF46, STANDOFF47, STANDOFF48: STAND-OFF
TP1, TP2, TP3, TP4, TP5, TP6, TP7, TP8, TP9, TP10, TP11, TP12: TEST-POINTTP_15TH_THRU; TP_15TH
U1, U2, U3, U4, U5, U6, U7, U8, U9, U10, U11, U12: L6470; HTSSOP28

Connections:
3.3V: C8.A, SJ1.1, TP1.P$1, U1.6
3.3V1: C16.A, SJ4.1, TP2.P$1, U2.6
3.3V2: C24.A, SJ7.1, TP3.P$1, U3.6
3.3V3: C32.A, SJ10.1, TP4.P$1, U4.6
3.3V4: C40.A, SJ13.1, TP5.P$1, U5.6
3.3V5: C48.A, SJ16.1, TP6.P$1, U6.6
3.3V6: C56.A, SJ19.1, TP7.P$1, U7.6
3.3V7: C64.A, SJ22.1, TP8.P$1, U8.6
3.3V8: C72.A, SJ25.1, TP9.P$1, U9.6
3.3V9: C80.A, SJ28.1, TP10.P$1, U10.6
3.3V10: C88.A, SJ31.1, TP11.P$1, U11.6
3.3V11: C96.A, SJ34.1, TP12.P$1, U12.6
5V: JP1.1, JP1.10, JP2.1, JP2.10, SJ1.3
5V1: JP10.1, JP10.10, JP15.1, JP15.10, SJ4.3
5V2: JP19.1, JP19.10, JP24.1, JP24.10, SJ7.3
5V3: JP28.1, JP28.10, JP33.1, JP33.10, SJ10.3
5V4: JP37.1, JP37.10, JP42.1, JP42.10, SJ13.3
5V5: JP46.1, JP46.10, JP51.1, JP51.10, SJ16.3
5V6: JP55.1, JP55.10, JP60.1, JP60.10, SJ19.3
5V7: JP64.1, JP64.10, JP69.1, JP69.10, SJ22.3
5V8: JP73.1, JP73.10, JP78.1, JP78.10, SJ25.3
5V9: JP82.1, JP82.10, JP87.1, JP87.10, SJ28.3
5V10: JP91.1, JP91.10, JP96.1, JP96.10, SJ31.3
5V11: JP100.1, JP100.10, JP105.1, JP105.10, SJ34.3
ADC: R4.P$2, R4.P$3, R5.2, U1.5
ADC1: R10.P$2, R10.P$3, R11.2, U2.5
ADC2: R16.P$2, R16.P$3, R17.2, U3.5
ADC3: R22.P$2, R22.P$3, R23.2, U4.5
ADC4: R28.P$2, R28.P$3, R29.2, U5.5
ADC5: R34.P$2, R34.P$3, R35.2, U6.5
ADC6: R40.P$2, R40.P$3, R41.2, U7.5
ADC7: R46.P$2, R46.P$3, R47.2, U8.5
ADC8: R52.P$2, R52.P$3, R53.2, U9.5
ADC9: R58.P$2, R58.P$3, R59.2, U10.5
ADC10: R64.P$2, R64.P$3, R65.2, U11.5
ADC11: R70.P$2, R70.P$3, R71.2, U12.5
BUSYN: JP3.2, JP4.2, R1.1, U1.22
BUSYN1: JP17.2, JP18.2, R7.1, U2.22
BUSYN2: JP26.2, JP27.2, R13.1, U3.22
BUSYN3: JP35.2, JP36.2, R19.1, U4.22
BUSYN4: JP44.2, JP45.2, R25.1, U5.22
BUSYN5: JP53.2, JP54.2, R31.1, U6.22
BUSYN6: JP62.2, JP63.2, R37.1, U7.22
BUSYN7: JP71.2, JP72.2, R43.1, U8.22
BUSYN8: JP80.2, JP81.2, R49.1, U9.22
BUSYN9: JP89.2, JP90.2, R55.1, U10.22
BUSYN10: JP98.2, JP99.2, R61.1, U11.22
BUSYN11: JP107.2, JP108.2, R67.1, U12.22
CP_HIGH: C6.1, D1.3
CP_HIGH1: C11.1, D2.3
CP_HIGH2: C19.1, D3.3
CP_HIGH3: C27.1, D4.3
CP_HIGH4: C35.1, D5.3
CP_HIGH5: C43.1, D6.3
CP_HIGH6: C51.1, D7.3
CP_HIGH7: C59.1, D8.3
CP_HIGH8: C67.1, D9.3
CP_HIGH9: C75.1, D10.3
CP_HIGH10: C83.1, D11.3
CP_HIGH11: C91.1, D12.3
CSN: JP1.3, JP2.3, U1.23
CSN1: JP10.3, JP15.3, U2.23
CSN2: JP19.3, JP24.3, U3.23
CSN3: JP28.3, JP33.3, U4.23
CSN4: JP37.3, JP42.3, U5.23
CSN5: JP46.3, JP51.3, U6.23
CSN6: JP55.3, JP60.3, U7.23
CSN7: JP64.3, JP69.3, U8.23
CSN8: JP73.3, JP78.3, U9.23
CSN9: JP82.3, JP87.3, U10.23
CSN10: JP91.3, JP96.3, U11.23
CSN11: JP100.3, JP105.3, U12.23
D_RETURN: JP1.4, JP2.4, SJ3.3
D_RETURN1: JP10.4, JP15.4, SJ6.3
D_RETURN2: JP19.4, JP24.4, SJ9.3
D_RETURN3: JP28.4, JP33.4, SJ12.3
D_RETURN4: JP37.4, JP42.4, SJ15.3
D_RETURN5: JP46.4, JP51.4, SJ18.3
D_RETURN6: JP55.4, JP60.4, SJ21.3
D_RETURN7: JP64.4, JP69.4, SJ24.3
D_RETURN8: JP73.4, JP78.4, SJ27.3
D_RETURN9: JP82.4, JP87.4, SJ30.3
D_RETURN10: JP91.4, JP96.4, SJ33.3
D_RETURN11: JP100.4, JP105.4, SJ36.3
FLAGN: JP3.3, JP4.3, R2.1, U1.24
FLAGN1: JP17.3, JP18.3, R8.1, U2.24
FLAGN2: JP26.3, JP27.3, R14.1, U3.24
FLAGN3: JP35.3, JP36.3, R20.1, U4.24
FLAGN4: JP44.3, JP45.3, R26.1, U5.24
FLAGN5: JP53.3, JP54.3, R32.1, U6.24
FLAGN6: JP62.3, JP63.3, R38.1, U7.24
FLAGN7: JP71.3, JP72.3, R44.1, U8.24
FLAGN8: JP80.3, JP81.3, R50.1, U9.24
FLAGN9: JP89.3, JP90.3, R56.1, U10.24
FLAGN10: JP98.3, JP99.3, R62.1, U11.24
FLAGN11: JP107.3, JP108.3, R68.1, U12.24
GND: C1.2, C2.C, C7.2, C8.C, JP1.2, JP1.9, JP2.2, JP2.9, JP3.5, JP4.5, JP5.2, R5.1, SJ2.P$1, U1.9, U1.21
GND1: C9.2, C10.C, C15.2, C16.C, JP10.2, JP10.9, JP14.2, JP15.2, JP15.9, JP17.5, JP18.5, R11.1, SJ5.P$1, U2.9, U2.21
GND2: C17.2, C18.C, C23.2, C24.C, JP19.2, JP19.9, JP23.2, JP24.2, JP24.9, JP26.5, JP27.5, R17.1, SJ8.P$1, U3.9, U3.21
GND3: C25.2, C26.C, C31.2, C32.C, JP28.2, JP28.9, JP32.2, JP33.2, JP33.9, JP35.5, JP36.5, R23.1, SJ11.P$1, U4.9, U4.21
GND4: C33.2, C34.C, C39.2, C40.C, JP37.2, JP37.9, JP41.2, JP42.2, JP42.9, JP44.5, JP45.5, R29.1, SJ14.P$1, U5.9, U5.21
GND5: C41.2, C42.C, C47.2, C48.C, JP46.2, JP46.9, JP50.2, JP51.2, JP51.9, JP53.5, JP54.5, R35.1, SJ17.P$1, U6.9, U6.21
GND6: C49.2, C50.C, C55.2, C56.C, JP55.2, JP55.9, JP59.2, JP60.2, JP60.9, JP62.5, JP63.5, R41.1, SJ20.P$1, U7.9, U7.21
GND7: C57.2, C58.C, C63.2, C64.C, JP64.2, JP64.9, JP68.2, JP69.2, JP69.9, JP71.5, JP72.5, R47.1, SJ23.P$1, U8.9, U8.21
GND8: C65.2, C66.C, C71.2, C72.C, JP73.2, JP73.9, JP77.2, JP78.2, JP78.9, JP80.5, JP81.5, R53.1, SJ26.P$1, U9.9, U9.21
GND9: C73.2, C74.C, C79.2, C80.C, JP82.2, JP82.9, JP86.2, JP87.2, JP87.9, JP89.5, JP90.5, R59.1, SJ29.P$1, U10.9, U10.21
GND10: C81.2, C82.C, C87.2, C88.C, JP91.2, JP91.9, JP95.2, JP96.2, JP96.9, JP98.5, JP99.5, R65.1, SJ32.P$1, U11.9, U11.21
GND11: C89.2, C90.C, C95.2, C96.C, JP100.2, JP100.9, JP104.2, JP105.2, JP105.9, JP107.5, JP108.5, R71.1, SJ35.P$1, U12.9, U12.21
unnamed: R10.P$1, R12.1
unnamed: R16.P$1, R18.1
unnamed: R22.P$1, R24.1
unnamed: R28.P$1, R30.1
unnamed: R34.P$1, R36.1
unnamed: R40.P$1, R42.1
unnamed: R46.P$1, R48.1
unnamed: R52.P$1, R54.1
unnamed: R58.P$1, R60.1
unnamed: R64.P$1, R66.1
unnamed: R4.P$1, R6.1
unnamed: R70.P$1, R72.1
OSCIN: JP1.7, JP1.8, U1.7
OSCIN1: JP15.7, JP15.8, U2.7
OSCIN2: JP24.7, JP24.8, U3.7
OSCIN3: JP33.7, JP33.8, U4.7
OSCIN4: JP42.7, JP42.8, U5.7
OSCIN5: JP51.7, JP51.8, U6.7
OSCIN6: JP60.7, JP60.8, U7.7
OSCIN7: JP69.7, JP69.8, U8.7
OSCIN8: JP78.7, JP78.8, U9.7
OSCIN9: JP87.7, JP87.8, U10.7
OSCIN10: JP96.7, JP96.8, U11.7
OSCIN11: JP105.7, JP105.8, U12.7
OSCOUT: JP2.7, JP2.8, U1.8
OSCOUT1: JP10.7, JP10.8, U2.8
OSCOUT2: JP19.7, JP19.8, U3.8
OSCOUT3: JP28.7, JP28.8, U4.8
OSCOUT4: JP37.7, JP37.8, U5.8
OSCOUT5: JP46.7, JP46.8, U6.8
OSCOUT6: JP55.7, JP55.8, U7.8
OSCOUT7: JP64.7, JP64.8, U8.8
OSCOUT8: JP73.7, JP73.8, U9.8
OSCOUT9: JP82.7, JP82.8, U10.8
OSCOUT10: JP91.7, JP91.8, U11.8
OSCOUT11: JP100.7, JP100.8, U12.8
OUT1A: JP8.2, U1.1
OUT1A1: JP12.2, U2.1
OUT1A2: JP21.2, U3.1
OUT1A3: JP30.2, U4.1
OUT1A4: JP39.2, U5.1
OUT1A5: JP48.2, U6.1
OUT1A6: JP57.2, U7.1
OUT1A7: JP66.2, U8.1
OUT1A8: JP75.2, U9.1
OUT1A9: JP84.2, U10.1
OUT1A10: JP93.2, U11.1
OUT1A11: JP102.2, U12.1
OUT1B: JP9.1, U1.14
OUT1B1: JP13.1, U2.14
OUT1B2: JP22.1, U3.14
OUT1B3: JP31.1, U4.14
OUT1B4: JP40.1, U5.14
OUT1B5: JP49.1, U6.14
OUT1B6: JP58.1, U7.14
OUT1B7: JP67.1, U8.14
OUT1B8: JP76.1, U9.14
OUT1B9: JP85.1, U10.14
OUT1B10: JP94.1, U11.14
OUT1B11: JP103.1, U12.14
OUT2A: JP8.1, U1.28
OUT2A1: JP12.1, U2.28
OUT2A2: JP21.1, U3.28
OUT2A3: JP30.1, U4.28
OUT2A4: JP39.1, U5.28
OUT2A5: JP48.1, U6.28
OUT2A6: JP57.1, U7.28
OUT2A7: JP66.1, U8.28
OUT2A8: JP75.1, U9.28
OUT2A9: JP84.1, U10.28
OUT2A10: JP93.1, U11.28
OUT2A11: JP102.1, U12.28
OUT2B: JP9.2, U1.15
OUT2B1: JP13.2, U2.15
OUT2B2: JP22.2, U3.15
OUT2B3: JP31.2, U4.15
OUT2B4: JP40.2, U5.15
OUT2B5: JP49.2, U6.15
OUT2B6: JP58.2, U7.15
OUT2B7: JP67.2, U8.15
OUT2B8: JP76.2, U9.15
OUT2B9: JP85.2, U10.15
OUT2B10: JP94.2, U11.15
OUT2B11: JP103.2, U12.15
PGND: C3.-, C4.2, JP7.1, JP7.2, SJ2.P$2, U1.13, U1.27, U1.29
PGND1: C13.2, C14.-, JP11.1, JP11.2, SJ5.P$2, U2.13, U2.27, U2.29
PGND2: C21.2, C22.-, JP20.1, JP20.2, SJ8.P$2, U3.13, U3.27, U3.29
PGND3: C29.2, C30.-, JP29.1, JP29.2, SJ11.P$2, U4.13, U4.27, U4.29
PGND4: C37.2, C38.-, JP38.1, JP38.2, SJ14.P$2, U5.13, U5.27, U5.29
PGND5: C45.2, C46.-, JP47.1, JP47.2, SJ17.P$2, U6.13, U6.27, U6.29
PGND6: C53.2, C54.-, JP56.1, JP56.2, SJ20.P$2, U7.13, U7.27, U7.29
PGND7: C61.2, C62.-, JP65.1, JP65.2, SJ23.P$2, U8.13, U8.27, U8.29
PGND8: C69.2, C70.-, JP74.1, JP74.2, SJ26.P$2, U9.13, U9.27, U9.29
PGND9: C77.2, C78.-, JP83.1, JP83.2, SJ29.P$2, U10.13, U10.27, U10.29
PGND10: C85.2, C86.-, JP92.1, JP92.2, SJ32.P$2, U11.13, U11.27, U11.29
PGND11: C93.2, C94.-, JP101.1, JP101.2, SJ35.P$2, U12.13, U12.27, U12.29
RESETN: JP3.1, JP4.1, U1.3
RESETN1: JP17.1, JP18.1, U2.3
RESETN2: JP26.1, JP27.1, U3.3
RESETN3: JP35.1, JP36.1, U4.3
RESETN4: JP44.1, JP45.1, U5.3
RESETN5: JP53.1, JP54.1, U6.3
RESETN6: JP62.1, JP63.1, U7.3
RESETN7: JP71.1, JP72.1, U8.3
RESETN8: JP80.1, JP81.1, U9.3
RESETN9: JP89.1, JP90.1, U10.3
RESETN10: JP98.1, JP99.1, U11.3
RESETN11: JP107.1, JP108.1, U12.3
SCK: JP1.6, JP2.6, U1.19
SCK1: JP10.6, JP15.6, U2.19
SCK2: JP19.6, JP24.6, U3.19
SCK3: JP28.6, JP33.6, U4.19
SCK4: JP37.6, JP42.6, U5.19
SCK5: JP46.6, JP51.6, U6.19
SCK6: JP55.6, JP60.6, U7.19
SCK7: JP64.6, JP69.6, U8.19
SCK8: JP73.6, JP78.6, U9.19
SCK9: JP82.6, JP87.6, U10.19
SCK10: JP91.6, JP96.6, U11.19
SCK11: JP100.6, JP105.6, U12.19
SDI: JP1.5, U1.20
SDI1: JP15.5, U2.20
SDI2: JP24.5, U3.20
SDI3: JP33.5, U4.20
SDI4: JP42.5, U5.20
SDI5: JP51.5, U6.20
SDI6: JP60.5, U7.20
SDI7: JP69.5, U8.20
SDI8: JP78.5, U9.20
SDI9: JP87.5, U10.20
SDI10: JP96.5, U11.20
SDI11: JP105.5, U12.20
SDO: SJ3.2, U1.18
SDO1: SJ6.2, U2.18
SDO2: SJ9.2, U3.18
SDO3: SJ12.2, U4.18
SDO4: SJ15.2, U5.18
SDO5: SJ18.2, U6.18
SDO6: SJ21.2, U7.18
SDO7: SJ24.2, U8.18
SDO8: SJ27.2, U9.18
SDO9: SJ30.2, U10.18
SDO10: SJ33.2, U11.18
SDO11: SJ36.2, U12.18
SDO_DOWNSTREAM: JP2.5, SJ3.1
SDO_DOWNSTREAM1: JP10.5, SJ6.1
SDO_DOWNSTREAM2: JP19.5, SJ9.1
SDO_DOWNSTREAM3: JP28.5, SJ12.1
SDO_DOWNSTREAM4: JP37.5, SJ15.1
SDO_DOWNSTREAM5: JP46.5, SJ18.1
SDO_DOWNSTREAM6: JP55.5, SJ21.1
SDO_DOWNSTREAM7: JP64.5, SJ24.1
SDO_DOWNSTREAM8: JP73.5, SJ27.1
SDO_DOWNSTREAM9: JP82.5, SJ30.1
SDO_DOWNSTREAM10: JP91.5, SJ33.1
SDO_DOWNSTREAM11: JP100.5, SJ36.1
STCK: JP3.6, JP4.6, U1.25
STCK1: JP17.6, JP18.6, U2.25
STCK2: JP26.6, JP27.6, U3.25
STCK3: JP35.6, JP36.6, U4.25
STCK4: JP44.6, JP45.6, U5.25
STCK5: JP53.6, JP54.6, U6.25
STCK6: JP62.6, JP63.6, U7.25
STCK7: JP71.6, JP72.6, U8.25
STCK8: JP80.6, JP81.6, U9.25
STCK9: JP89.6, JP90.6, U10.25
STCK10: JP98.6, JP99.6, U11.25
STCK11: JP107.6, JP108.6, U12.25
SWITCH_INPUT: C7.1, JP5.1, R3.2
SWITCH_INPUT1: C15.1, JP14.1, R9.2
SWITCH_INPUT2: C23.1, JP23.1, R15.2
SWITCH_INPUT3: C31.1, JP32.1, R21.2
SWITCH_INPUT4: C39.1, JP41.1, R27.2
SWITCH_INPUT5: C47.1, JP50.1, R33.2
SWITCH_INPUT6: C55.1, JP59.1, R39.2
SWITCH_INPUT7: C63.1, JP68.1, R45.2
SWITCH_INPUT8: C71.1, JP77.1, R51.2
SWITCH_INPUT9: C79.1, JP86.1, R57.2
SWITCH_INPUT10: C87.1, JP95.1, R63.2
SWITCH_INPUT11: C95.1, JP104.1, R69.2
SWITCH_SIG: R3.1, U1.4
SWITCH_SIG1: R9.1, U2.4
SWITCH_SIG2: R15.1, U3.4
SWITCH_SIG3: R21.1, U4.4
SWITCH_SIG4: R27.1, U5.4
SWITCH_SIG5: R33.1, U6.4
SWITCH_SIG6: R39.1, U7.4
SWITCH_SIG7: R45.1, U8.4
SWITCH_SIG8: R51.1, U9.4
SWITCH_SIG9: R57.1, U10.4
SWITCH_SIG10: R63.1, U11.4
SWITCH_SIG11: R69.1, U12.4
VLOGIC: C1.1, C2.A, R1.2, R2.2, SJ1.2, U1.17
VLOGIC1: C9.1, C10.A, R7.2, R8.2, SJ4.2, U2.17
VLOGIC2: C17.1, C18.A, R13.2, R14.2, SJ7.2, U3.17
VLOGIC3: C25.1, C26.A, R19.2, R20.2, SJ10.2, U4.17
VLOGIC4: C33.1, C34.A, R25.2, R26.2, SJ13.2, U5.17
VLOGIC5: C41.1, C42.A, R31.2, R32.2, SJ16.2, U6.17
VLOGIC6: C49.1, C50.A, R37.2, R38.2, SJ19.2, U7.17
VLOGIC7: C57.1, C58.A, R43.2, R44.2, SJ22.2, U8.17
VLOGIC8: C65.1, C66.A, R49.2, R50.2, SJ25.2, U9.17
VLOGIC9: C73.1, C74.A, R55.2, R56.2, SJ28.2, U10.17
VLOGIC10: C81.1, C82.A, R61.2, R62.2, SJ31.2, U11.17
VLOGIC11: C89.1, C90.A, R67.2, R68.2, SJ34.2, U12.17
VS: C3.+, C4.1, C5.2, D1.1, JP6.1, JP6.2, R6.2, U1.2, U1.12, U1.16, U1.26
VS1: C12.2, C13.1, C14.+, D2.1, JP16.1, JP16.2, R12.2, U2.2, U2.12, U2.16, U2.26
VS2: C20.2, C21.1, C22.+, D3.1, JP25.1, JP25.2, R18.2, U3.2, U3.12, U3.16, U3.26
VS3: C28.2, C29.1, C30.+, D4.1, JP34.1, JP34.2, R24.2, U4.2, U4.12, U4.16, U4.26
VS4: C36.2, C37.1, C38.+, D5.1, JP43.1, JP43.2, R30.2, U5.2, U5.12, U5.16, U5.26
VS5: C44.2, C45.1, C46.+, D6.1, JP52.1, JP52.2, R36.2, U6.2, U6.12, U6.16, U6.26
VS6: C52.2, C53.1, C54.+, D7.1, JP61.1, JP61.2, R42.2, U7.2, U7.12, U7.16, U7.26
VS7: C60.2, C61.1, C62.+, D8.1, JP70.1, JP70.2, R48.2, U8.2, U8.12, U8.16, U8.26
VS8: C68.2, C69.1, C70.+, D9.1, JP79.1, JP79.2, R54.2, U9.2, U9.12, U9.16, U9.26
VS9: C76.2, C77.1, C78.+, D10.1, JP88.1, JP88.2, R60.2, U10.2, U10.12, U10.16, U10.26
VS10: C84.2, C85.1, C86.+, D11.1, JP97.1, JP97.2, R66.2, U11.2, U11.12, U11.16, U11.26
VS11: C92.2, C93.1, C94.+, D12.1, JP106.1, JP106.2, R72.2, U12.2, U12.12, U12.16, U12.26
V_BOOT: C5.1, D1.2, U1.11
V_BOOT1: C12.1, D2.2, U2.11
V_BOOT2: C20.1, D3.2, U3.11
V_BOOT3: C28.1, D4.2, U4.11
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

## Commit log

2012-11-09 Initial commit, before review.
    [BabyDriver.brd, BabyDriver.sch]
2012-11-13 v01 files, as sent to protos.
    Mostly unchanged from initial commit; changed some part placements,
    some silk.
    [BabyDriver.brd, BabyDriver.sch]
2012-12-05 Adding the example code I wrote for the original L6470 driver board.
    Going to be quite thoroughly rejiggered for the new board, mostly for stylistic purposes.
2012-12-11 Tidying up the example code some; that's still in process.
    This is to update the hardware files to v02- shrink the board
    a bit.
    [BabyDriver.brd, BabyDriver.sch]
2012-12-18 Changes for v02- second proto round Shrank overall board size by about 15% Added a pad for extra chip select signal Improved text placement
    [BabyDriver.brd]
2013-02-18 Fix mask on bottom layer
    [BabyDriver.brd, BabyDriver.sch]
2013-06-19 Added four-layer warning to files.
    [BabyDriver.brd, BabyDriver.sch]
2013-06-27 Updated for v10 redboard
    [BabyDriver.brd, BabyDriver.sch]
2013-06-27 Add all files for v10, this time
    [L6470 AutoDriver.brd, L6470 AutoDriver.sch]
2013-06-27 Production ready
    created 4 board panel; added fiducials
    [L6470 AutoDriver Panel v10.brd, L6470 AutoDriver.brd, L6470 AutoDriver.sch]
2013-11-04 Reduce from 3 to 2 boards in example sketch
2013-11-04 Update library to full release version - Change SPI mode - Add a few funcs (setMinSpeed, get/set mark, get/set pos) - Move setLoSpdOpt()
2013-11-05 Fix SPI mode, dSPINConstants.h file
2013-11-05 Fix SPI again. Gr.
2014-06-24 Update dSPIN_example.ino
    Fixed the reset pin define so it matches the diagram in the tutorial.
2014-08-06 0603 update, Sch work, cap change
    Updated res/caps to 0603
    large cap updated to smaller silk/pad size
    jumper indicator added, OSHW logo upgraded
    [L6470 AutoDriver.brd, L6470 AutoDriver.sch]
2014-10-02 Moved via
    [L6470 AutoDriver.brd]
2014-10-07 Fixed bstop
    [L6470 AutoDriver.brd]
2014-10-07 fixed b stop
    [L6470 AutoDriver.brd]
2014-10-15 Connect CSN to CSN_OUT, minor fixes
    [L6470 AutoDriver.brd, L6470 AutoDriver.sch]
2014-12-19 Making changes suggest by Pete L
    [L6470 AutoDriver.brd, L6470 AutoDriver.sch]
2015-01-09 fixing bugs: OC & VC get/set, and MIN_SPEED
    OC (over current) and VC (voltage compensation) masking was incorrect.
    Fixed masks for read and write.
    MIN_SPEED packets were only transferring 12 (not 13 bits). Fixed.
2015-01-09 adding example arduino sketch: GetSetParamTest.ino
    Gets and sets a bunch of parameters and checks that the same value
    returns.
2015-04-03 declaring all chars as signed + standard SPI calls
2015-04-03 Switching to standard SPI library calls
2015-04-30 Fixed more feedback from Pete after 1st proto cam failure
    [L6470 AutoDriver.brd, L6470 AutoDriver.sch]
2015-05-04 Adjust file structure and add library readme
    [L6470 AutoDriver Panel v10.brd]
2015-05-04 Squashed 'Libraries/Arduino/' content from commit 72894eb
    git-subtree-dir: Libraries/Arduino
    git-subtree-split: 72894eb51289e93a6878a00568dc00134f6b6def
2015-09-10 Significant changes from customer feedback: - now more daisy chainable - labels changed to make more sense - Change C5 to 220nF
    [L6470 AutoDriver.brd, L6470 AutoDriver.sch]
2015-09-10 Changes from customer feedback: - now easier to daisy chain! - labels make more sense in light of daisy chaining - change C5 to 220nF
    [L6470 AutoDriver.brd, L6470 AutoDriver.sch]
2015-09-15 Fix minor stuff from QC feedback
    [L6470 AutoDriver.sch]
2016-06-28 Final file changes from revision
    [L6470 AutoDriver.brd, L6470 AutoDriver.sch]
2016-06-30 Removed revised by from board
    [L6470 AutoDriver.brd, L6470 AutoDriver.sch]
2016-07-01 created panel v12
    [L6470 AutoDriver Panel v10.brd, L6470-AutoDriver-Panel_v12.brd]
2016-07-06 Fixed BSilk to match TSilk, advanced version number
    [L6470 AutoDriver.brd, L6470 AutoDriver.sch]
2016-07-06 Fixed one more silk mistake
    [L6470 AutoDriver.brd]
2016-07-07 created panel v13
    [L6470AutoDriver-Panel_v13.brd]
2016-09-19 Squashed 'Libraries/Arduino/' changes from 72894eb..6ed7fd4
    6ed7fd4 Updating library properties version number
    a16b935 Updating hookup guide link
    21c0dcc Updating readme
    8d1e038 Fixed parameter transfer function
    beb4b9e Added in a couple of fixes from the community based on pull requests
    41d5bea Changes for v_13 of the hardware - supports multiple boards with one CS line - supports multiple SPI buses or a non-standard SPI bus
    git-subtree-split: 6ed7fd4061457c09a3958981510de2d607b29a32
    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
2016-12-01 Squashed 'Libraries/Arduino/' changes from 6ed7fd4..38ad4dd
    38ad4dd Fixed ABSPOS overflow error
    git-subtree-split: 38ad4dd967539faa12b01ab82b326de3283b527b
    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
2016-12-13 Squashed 'Libraries/Arduino/' changes from 38ad4dd..b0d59c0
    b0d59c0 Removed some debug printing
    3c951bd Fixed sign propagation issue
    git-subtree-split: b0d59c03c996b31586ec3b43881ccdcfdb33056c
    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
2017-08-02 motor status fix

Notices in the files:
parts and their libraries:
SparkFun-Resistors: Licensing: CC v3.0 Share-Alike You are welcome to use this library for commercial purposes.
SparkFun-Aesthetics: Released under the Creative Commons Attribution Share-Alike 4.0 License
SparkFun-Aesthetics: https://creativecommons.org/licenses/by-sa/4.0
